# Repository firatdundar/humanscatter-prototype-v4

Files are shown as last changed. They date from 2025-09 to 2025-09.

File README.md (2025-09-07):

# Humanscatter v4 — Low-Power Backscatter Wireless Communication Prototype  
**Summer Research Project at RISE Research Institutes of Sweden**  

<p align="center">
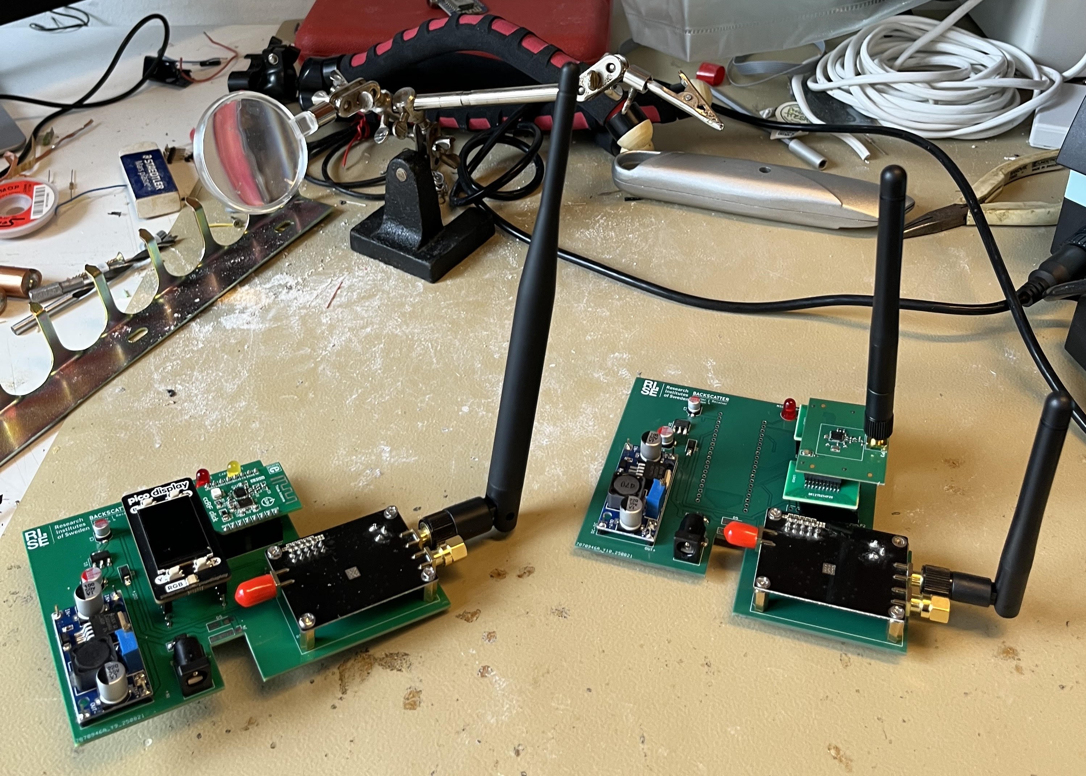
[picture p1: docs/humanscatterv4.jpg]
Humanscatter v4.1 and v4.2 Prototypes
  
</p>

Humanscatter v4 is an **enhanced version** of the [original Humanscatter project](https://github.com/amau75/Humanscatter), developed as part of a **summer research internship** at **RISE Research Institutes of Sweden**.  
This work focuses on **improving the range, reliability, and power stability** of a **low-power backscatter wireless communication prototype** for battery-free IoT applications.

---

## What's New in Humanscatter v4

### **v4.1**
- **Carrier module upgraded** to an **ADF4351 RF synthesizer** instead of CC2500.
- Added **AMS1117 3.3 V LDO regulator** for **cleaner and more stable power**.
- Improved range thanks to **better carrier control** and lower noise.
- Redesigned **KiCad PCB design** and updated **Raspberry Pi Pico firmware**.

### **v4.2**
- Built on top of v4.1 enhancements.
- **Receiver module upgraded** to a **CC2500 EMK evaluation kit**.
- Switched from a **trace antenna** to an **SMA-based external antenna** for better sensitivity.
- **AMS1117 regulator retained** for stable RF power delivery.
- Further improved range, carrier stability, and signal reliability.

---

## Hardware Overview

| Component | Original | v4.1 | v4.2 |
|---|---|---|---|
| **Carrier Module** | CC2500 | **ADF4351** (RF synthesizer) | **ADF4351** (RF synthesizer) |
| **Receiver Module**  | CC2500 (trace antenna) | CC2500 (trace antenna) | **CC2500 EMK** + **SMA antenna** |
| **Voltage Regulator**| None | **AMS1117 (3.3 V LDO)** | **AMS1117 (3.3 V LDO)** |
| **Microcontroller**  | Raspberry Pi Pico | Raspberry Pi Pico | Raspberry Pi Pico |
| **Antenna Type** | Trace PCB antenna | Trace PCB antenna | **SMA external antenna** |
| **PCB Design** | Original Humanscatter PCB  | Updated KiCad design | Updated KiCad design |

---

## Repository Structure

```

humanscatter-v4/
│
├── humanscatter-v4.1/
│   ├── kicad/           # KiCad schematic + PCB files for v4.1
│   └── firmware/        # Updated Raspberry Pi Pico code for v4.1
│
├── humanscatter-v4.2/
│   ├── kicad/           # KiCad schematic + PCB files for v4.2
│   └── firmware/        # Updated Raspberry Pi Pico code for v4.2
│
└── README.md            # This file

````

---

## Getting Started

### 1. Clone the Repository
```bash
git clone https://github.com/yourusername/humanscatter-v4.git
cd humanscatter-v4
````

### 2. Open KiCad Project

```bash
cd humanscatter-v4.1/kicad
open humanscatter-v4.1.kicad_pro
```

*(Same for `humanscatter-v4.2`.)*

### 3. Build and Flash Firmware

* Follow the same steps as in the [original Humanscatter project](https://github.com/amau75/Humanscatter).
* Replace the firmware files with the updated ones provided in the **`firmware/`** folder.
* Flash the code to the **Raspberry Pi Pico** using **Thonny** or any other MicroPython flashing tool.

##  Experimental Improvements

The key goals of this research were to **improve range**, **stability**, and **power delivery**.
Using the **ADF4351 RF synthesizer**, **AMS1117 regulator**, and an **SMA-based CC2500 EMK receiver**:

* Achieved **greater link distance** compared to original version.
* Improved **signal-to-noise ratio (SNR)**.
* Reduced **carrier frequency drift**.
* Increased **overall communication reliability**.

---

## License

This project builds upon the original [Humanscatter](https://github.com/amau75/Humanscatter)
and is released under the **CERN-OHL-P** open hardware license.

---

## Acknowledgements

* **Dr. Fehmi Ben Abdesslem** — for supervision and continuous support throughout the summer research
* **Amaury Couderc** — for the original Humanscatter project and guidance
* **RISE Research Institutes of Sweden** — for hosting and supporting the project

---

## 🔗 References

* Original Humanscatter repository: [https://github.com/amau75/Humanscatter](https://github.com/amau75/Humanscatter)
* ADF4351 RF Synthesizer Module: [Datasheet](https://www.analog.com/media/en/technical-documentation/data-sheets/ADF4351.pdf)
* CC2500 RF Transceiver: [Datasheet](https://www.ti.com/product/CC2500)
* AMS1117 Voltage Regulator: [Datasheet](http://www.advanced-monolithic.com/pdf/ds1117.pdf)

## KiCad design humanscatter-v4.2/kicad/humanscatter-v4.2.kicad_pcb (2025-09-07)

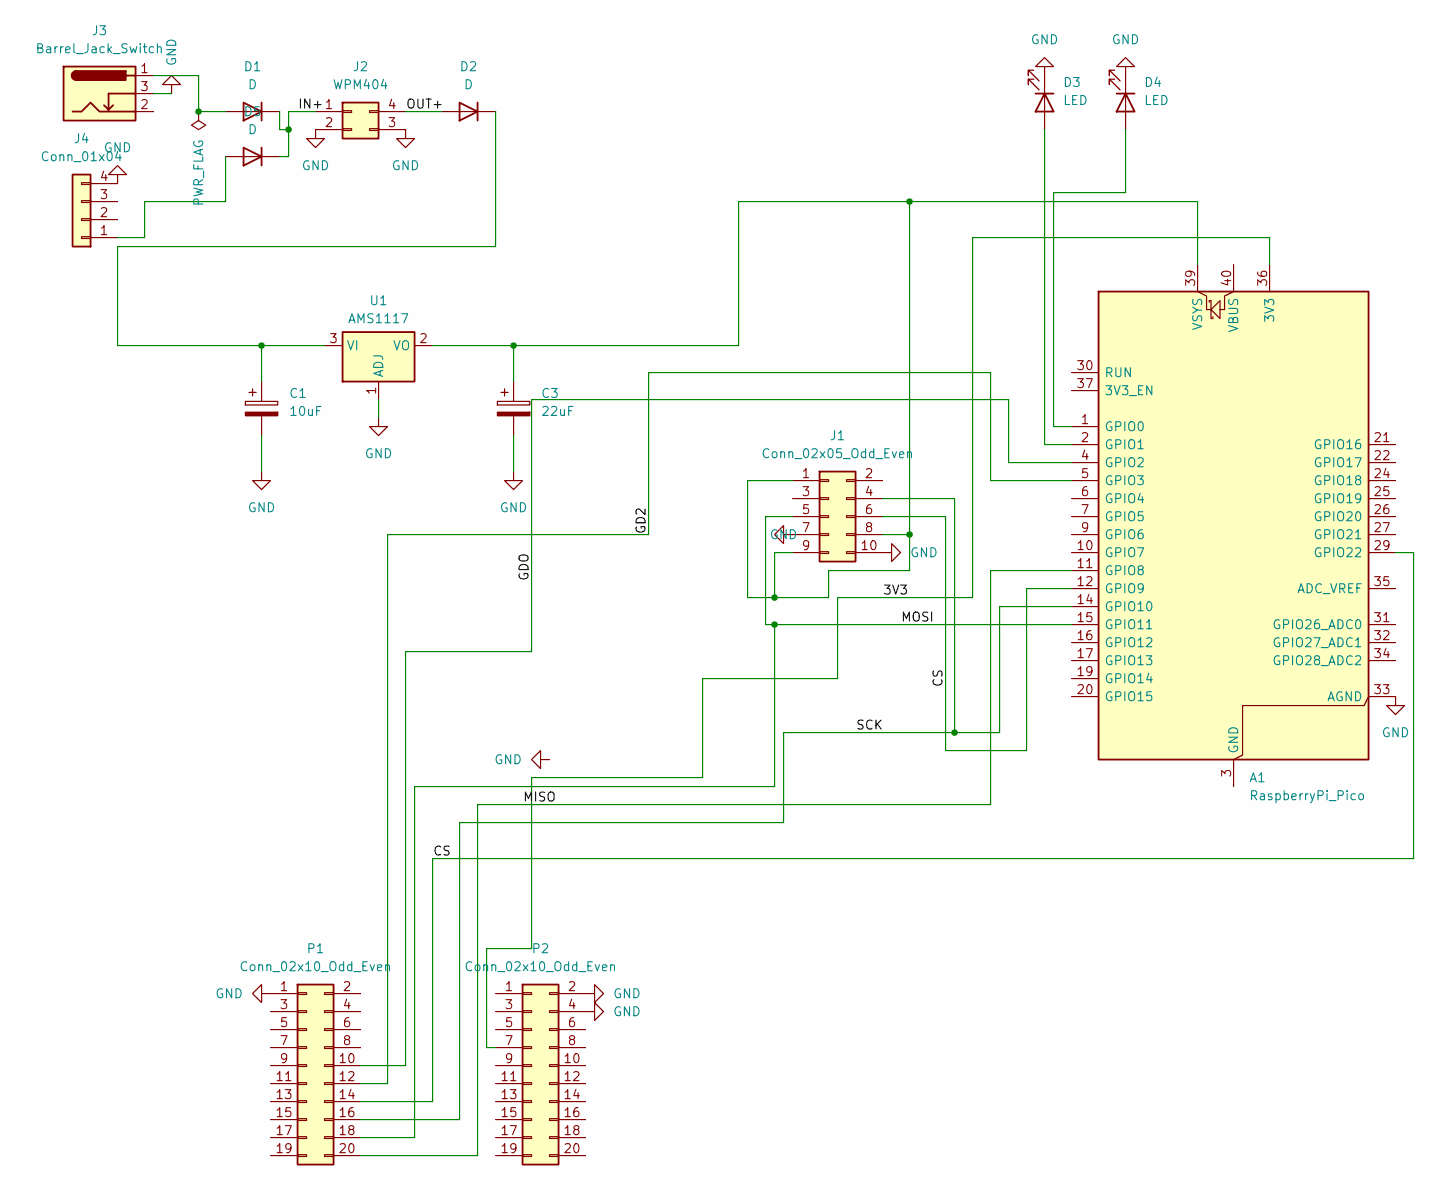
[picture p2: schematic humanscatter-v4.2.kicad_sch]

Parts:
A1: RaspberryPi_Pico; RaspberryPi_Pico_Common_THT
C1: 10uF; CP_Elec_6.3x5.4
C3: 22uF; CP_Elec_5x5.4
D1, D2, D5: D; D_SMA_Handsoldering
D3, D4: LED; LED_D5.0mm
J1: Conn_02x05_Odd_Even; PinSocket_2x05_P2.54mm_Vertical
J2: WPM404; WPM404_New
J3: Barrel_Jack_Switch; BarrelJack_Wuerth_6941xx301002
J4: Conn_01x04; PinHeader_1x04_P2.54mm_Vertical
P1, P2: Conn_02x10_Odd_Even; PinHeader_2x10_P1.27mm_Vertical
U1: AMS1117; SOT-223-3_TabPin2

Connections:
/3V3: A1.36 (3V3), P2.7
/CS: A1.12 (GPIO9), A1.29 (GPIO22), J1.6, P1.14
/GD2: A1.5 (GPIO3), P1.12
/GDO: A1.4 (GPIO2), P1.10
/IN+: D1.1 (K), D5.1 (K), J2.1
/MISO: A1.11 (GPIO8), P1.20
/MOSI: A1.15 (GPIO11), J1.5, P1.18
/OUT+: D2.2 (A), J2.4
/SCK: A1.14 (GPIO10), J1.4, P1.16
GND: A1.33 (AGND), C1.2, C3.2, D3.1 (K), D4.1 (K), J1.7, J1.10, J2.2, J2.3, J3.3, J4.4, P1.1, P2.2, P2.4, U1.1 (ADJ)
unnamed: A1.3 (GND), A1.8 (GND), A1.13 (GND), A1.18 (GND), A1.23 (GND), A1.28 (GND), A1.38 (GND)
unnamed: A1.1 (GPIO0), D4.2 (A)
unnamed: A1.2 (GPIO1), D3.2 (A)
unnamed: A1.39 (VSYS), C3.1, J1.1, J1.8, J1.9, U1.2 (VO)
unnamed: D1.2 (A), J3.1
unnamed: C1.1, D2.1 (K), U1.3 (VI)
unnamed: D5.2 (A), J4.1

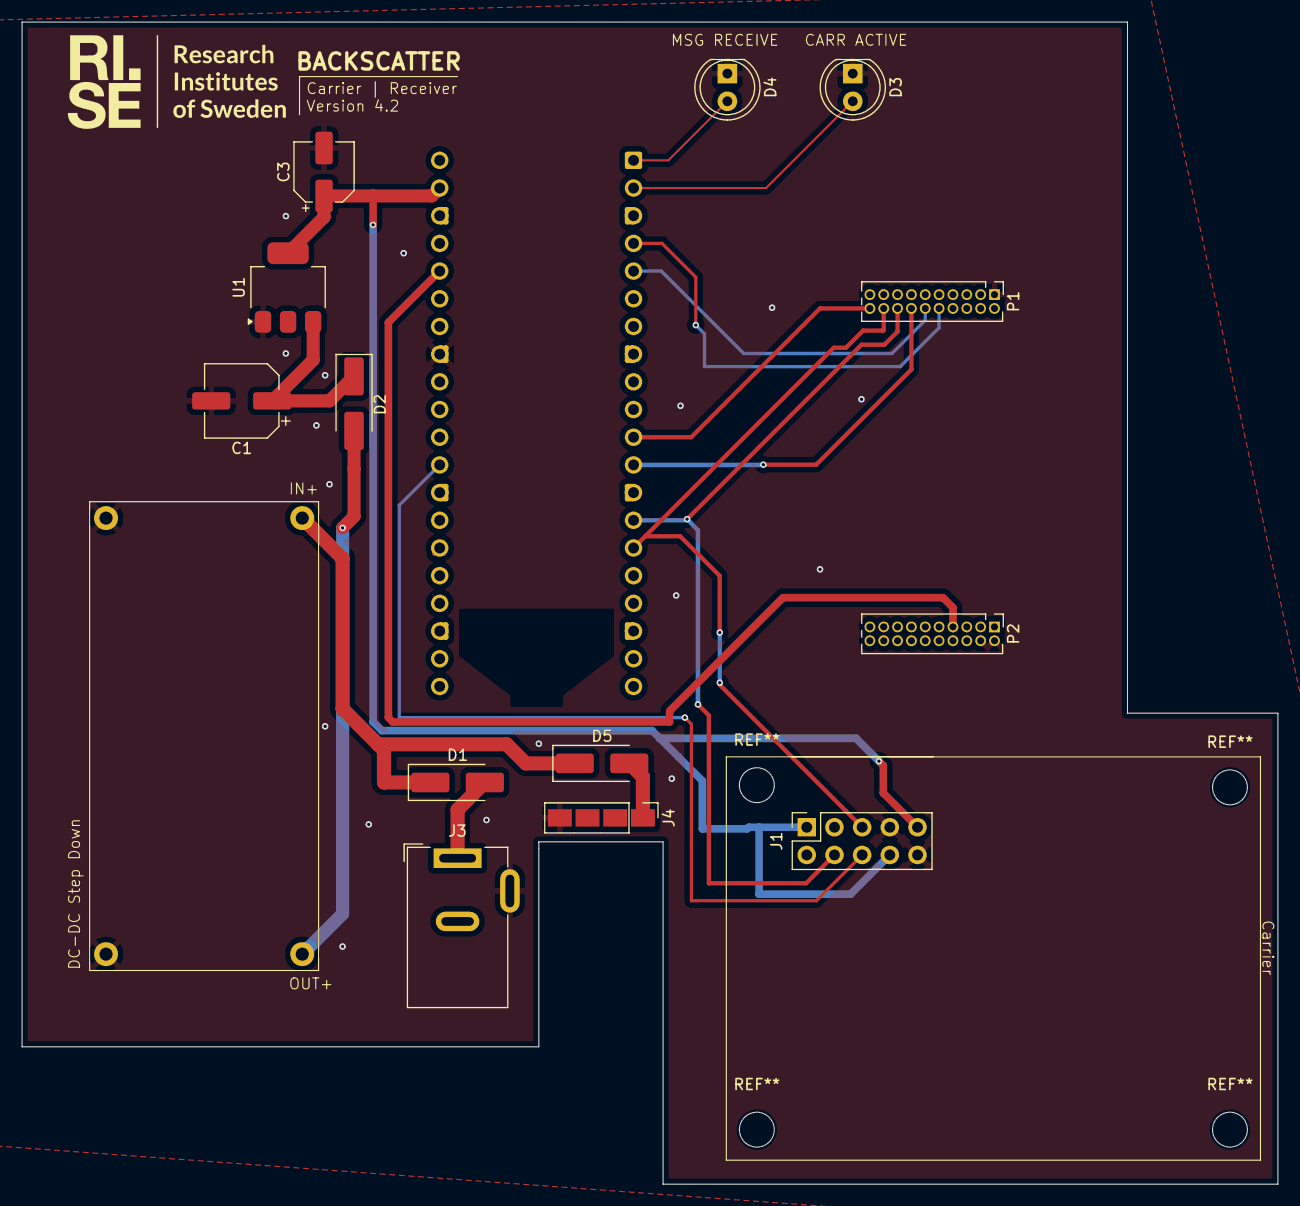
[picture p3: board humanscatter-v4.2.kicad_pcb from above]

Board: 2 copper layers, 115.2 x 106.6 mm, 15 parts (1 on the bottom side), 17 nets.

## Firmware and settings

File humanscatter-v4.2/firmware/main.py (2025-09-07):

import time
import machine
from machine import Pin, SPI

# ====================== SAFE IMPORTS ======================
try:
    from picographics import PicoGraphics, DISPLAY_PICO_DISPLAY, PEN_P4
except ImportError:
    print("[ERROR] PicoGraphics module not found! Check your UF2 firmware.")
    PicoGraphics = None

try:
    import carrier
    import receiver
    import display
except Exception as e:
    print("[ERROR] Failed to import local modules:", e)
    carrier = None
    receiver = None
    display = None

# ====================== BOOT DELAY ======================
print("[DEBUG] Waiting 3s before starting...")
time.sleep(3)

# ====================== PINS ======================
LED_CARRIER_PIN = 1   # GPIO1 → Carrier active LED
LED_MESSAGE_PIN = 0   # GPIO0 → Message received LED

RX_SCK = 10
RX_MISO = 8
RX_MOSI = 11
CS_RX_PIN = 22
GDO0_PIN = 2
GD2_PIN = 3   # optional

carrier_timeout = 20  # seconds

# ====================== LED SETUP ======================
try:
    LED_CARRIER = Pin(LED_CARRIER_PIN, Pin.OUT)
    LED_MESSAGE = Pin(LED_MESSAGE_PIN, Pin.OUT)

    # Reset LEDs
    LED_CARRIER.value(0)
    LED_MESSAGE.value(0)

    print("[DEBUG] LEDs initialized successfully!")

    # Test LEDs separately at boot
    print("[DEBUG] Testing LEDs...")
    LED_CARRIER.value(1)
    time.sleep(0.3)
    LED_CARRIER.value(0)
    time.sleep(0.2)
    LED_MESSAGE.value(1)
    time.sleep(0.3)
    LED_MESSAGE.value(0)
    print("[DEBUG] LED test complete!")

except Exception as e:
    print("[ERROR] Failed to initialize LEDs:", e)

# ====================== VBUS / POWER DETECTION ======================
VBUS_PIN = 24   # Physical pin 40 → VBUS sense
try:
    VBUS = machine.Pin(VBUS_PIN, machine.Pin.IN)
except:
    VBUS = None
    print("[WARN] VBUS pin not available!")

def is_usb_powered():
    if VBUS is None:
        return False
    return VBUS.value() == 1

# ====================== POWER LED INDICATOR ======================
try:
    if is_usb_powered():
        print("[DEBUG] USB power detected → Turning GPIO0 LED ON")
        LED_MESSAGE.value(1)
    else:
        print("[DEBUG] VSYS (external) power detected → Turning GPIO0 LED ON")
        LED_MESSAGE.value(1)
except Exception as e:
    print("[ERROR] Failed to set power LED:", e)


# ====================== DISPLAY SETUP ======================
display_humanscatter = None
color = None

if display and PicoGraphics:
    try:
        print("[DEBUG] Initializing Pico Display...")
        display_humanscatter, color = display.setup_screen()
        print("[DEBUG] Pico Display initialized successfully!")
    except Exception as e:
        print("[ERROR] Failed to initialize display:", e)
else:
    print("[WARN] Skipping display setup — PicoGraphics or display.py missing!")

# ====================== SPI RECEIVER SETUP ======================
radio = None
CS_RX = None
try:
    print("[DEBUG] Setting up SPI for CC2500 receiver...")
    radio = SPI(
        1,
        baudrate=5_000_000,
        polarity=0,
        phase=0,
        bits=8,
        firstbit=SPI.MSB,
        sck=Pin(RX_SCK),
        mosi=Pin(RX_MOSI),
        miso=Pin(RX_MISO)
    )
    CS_RX = Pin(CS_RX_PIN, Pin.OUT)
    print("[DEBUG] SPI configured successfully!")
except Exception as e:
    print("[ERROR] Failed to configure SPI:", e)

# ====================== CARRIER SETUP ======================
if carrier:
    try:
        print("[DEBUG] Setting up ADF4351 carrier...")
        carrier.setup_TX()
        print("[DEBUG] ADF4351 setup complete!")
    except Exception as e:
        print("[ERROR] Carrier setup failed:", e)

# ====================== RECEIVER SETUP ======================
if receiver and radio and CS_RX:
    try:
        print("[DEBUG] Setting up CC2500 receiver...")
        receiver.setup_RX(radio, CS_RX, GDO0_PIN)
        print("[DEBUG] CC2500 receiver setup complete!")
    except Exception as e:
        print("[ERROR] Receiver setup failed:", e)

time.sleep_us(100)

# ====================== START CARRIER ======================
if carrier:
    try:
        print("[DEBUG] Starting carrier TX...")
        carrier.start_carrier_TX()
        LED_CARRIER.value(1)  # Turn carrier LED ON
        print("[DEBUG] Carrier started successfully!")
    except Exception as e:
        print("[ERROR] Failed to start carrier:", e)

# ====================== START RECEIVER ======================
if receiver and radio and CS_RX:
    try:
        print("[DEBUG] Starting receiver listening mode...")
        receiver.start_listen_RX(radio, CS_RX)
        receiver.event_RX = "no_reception"
        print("[DEBUG] Receiver listening mode active!")
    except Exception as e:
        print("[ERROR] Failed to start receiver:", e)

# ====================== INITIAL EVENTS ======================
if receiver and carrier:
    receiver.event_RX = "no_reception"
    carrier.event_TX = "no_timeout"
    print(f"[DEBUG] Initial RX event: {receiver.event_RX}")
    print(f"[DEBUG] Initial TX event: {carrier.event_TX}")

# ====================== MAIN LOOP ======================
cnt = 1
cnt2 = 0

if receiver and carrier:
    try:
        receiver.dummy_message_generator()
        carrier.carrier_timer(carrier_timeout)
    except Exception as e:
        print("[ERROR] Failed to start timers:", e)

print("[DEBUG] Entering main loop...")

try:
    while True:
        # If receiver got a message
        if receiver and receiver.event_RX == "reception":
            try:
                print("[DEBUG] Message received!")
                message = receiver.decode_packet_RX(
                    radio, CS_RX, receiver.RX_BUFFER_SIZE, receiver.Message()
                )

                # Blink message LED when message is received
                LED_MESSAGE.value(1)
                time.sleep_ms(100)
                LED_MESSAGE.value(0)

                # Demo messages
                if cnt2 == 0:
                    message.data = "Hello je backscatte comment ça va le sang"
                    message.RSSI += 5
                elif cnt2 == 1:
                    message.data = "Salut je suis Amaury, étudiant à RISE"
                    message.RSSI += 3
                elif cnt2 == 2:
                    message.data = "J'adore la Suède, super pays!"
                    message.RSSI += 8

                cnt2 = (cnt2 + 1) % 3

                receiver.print_RX(message)

                if display_humanscatter:
                    display.print_msg(display_humanscatter, message, color)

                time.sleep_ms(2000)
                receiver.start_listen_RX(radio, CS_RX)
                receiver.event_RX = "no_reception"
                cnt = 1
            except Exception as e:
                print("[ERROR] Failed during reception:", e)

        # If no messages yet
        elif receiver and receiver.event_RX == "no_reception":
            if cnt:
                print("[DEBUG] Waiting for messages...")
                if display_humanscatter:
                    display.print_waiting(display_humanscatter, "WAITING", color)
                cnt = 0

        # Carrier timeout
        elif carrier and carrier.event_TX == "timeout":
            print("[DEBUG] Carrier timeout! Stopping...")
            carrier.stop_carrier_TX()
            LED_CARRIER.value(0)  # Turn carrier LED OFF
            if display_humanscatter:
                display.print_carrier_timeout(display_humanscatter, color)
            break

        time.sleep(0.05)

except Exception as e:
    print("[FATAL] Crash in main loop:", e)
    print("[INFO] Entering safe idle mode...")
    while True:
        time.sleep(1)  # Keep USB REPL alive

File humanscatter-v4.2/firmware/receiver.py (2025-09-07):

import time
import carrier
import machine
import math
from machine import Pin, SPI, ADC, Timer
from picographics import PicoGraphics, DISPLAY_PICO_DISPLAY, PEN_P4

#================ VARIABLES =============

# Print Receiver Radio Configuration
config_prints = False

# Radio Parameters
BAUDRATE = 100000
F_XOSC = 26000000
CARRIER_FEQ = 2450000000
RX_BUFFER_SIZE = 64

# Values
r_data = 100000
bw = 794444
f_dev = 347222
f_carrier = 6597222

# --- NEW PIN CONFIGURATION ---
PIN_SCK = 10
PIN_MOSI = 11
PIN_MISO = 8
PIN_CS = 22
PIN_GDO0 = 2
PIN_GD2 = 3

# SPI initialization
spi_rx = SPI(
    1,
    baudrate=BAUDRATE,
    polarity=0,
    phase=0,
    bits=8,
    firstbit=SPI.MSB,
    sck=Pin(PIN_SCK),
    mosi=Pin(PIN_MOSI),
    miso=Pin(PIN_MISO)
)

# Chip Select Pin
cs_rx = Pin(PIN_CS, Pin.OUT)
cs_rx.value(1)  # Active low

# Interrupt pins
gdo0_pin = Pin(PIN_GDO0, Pin.IN)
gd2_pin = Pin(PIN_GD2, Pin.IN)

#================ REST OF CODE =============

# Strobes
SIDLE = 0x36    #Idle mode of radio
SRX = 0x34      #Receive mode of radio
SFRX = 0x3A     #Clear FIFO
SRES = 0x30     #Reset radio

# Registers
cc2500_receiver_settings=[[0x02, 0x06],
                          [0x08, 0x05],
                          [0x0b, 0x0A],
                          [0x0e, 0x7C],
                          [0x0f, 0x08],
                          [0x10, 0x0B],
                          [0x11, 0xF1],
                          [0x12, 0x03],
                          [0x13, 0x23],
                          [0x14, 0xFF],
                          [0x15, 0x76],
                          [0x18, 0x18],
                          [0x19, 0x1D],
                          [0x1a, 0x1C],
                          [0x1b, 0xC7],
                          [0x1c, 0x00],
                          [0x1d, 0xB0],
                          [0x21, 0xB6],
                          [0x25, 0x00],
                          [0x26, 0x11]]


class Message:
    data = ""
    overflow = 0
    RSSI = 0
    CRC = 0
    length = 0
    sequence = 0
    link_quality_indicator = 0

#================ FUNCTIONS =============

#-------------- setup functions --------------

def setup_RX(spi, CS, Pin_interrupt):
    write_strobe_RX(spi, CS, SRES)
    time.sleep_us(100)
    write_strobe_RX(spi, CS, SIDLE)
    
    write_register_RX(spi, CS, cc2500_receiver_settings)
    if (config_prints):
        print("set spi config  RX:")
        print([f"0x{byte:02X}" for pair in cc2500_receiver_settings for byte in pair])
        print(cc2500_receiver_settings)
    set_irq_RX(Pin_interrupt)
    set_frequency_RX(spi, CS, f_carrier + CARRIER_FEQ)
    set_freq_deviation_RX(spi, CS, f_dev)
    set_datarate_RX(spi, CS, r_data)
    set_filter_bandwidth_RX(spi, CS, bw)
    write_register_RX(spi, CS, [[0x10,0x0B]])

def interrupt_handler_RX(Pin):
    global event
    event = "reception"
    
def set_irq_RX(Pin_interrupt):
    interrupt_pin = machine.Pin(Pin_interrupt, mode=Pin.IN)
    interrupt_pin.irq(trigger=Pin.IRQ_FALLING,handler=interrupt_handler_RX)

#-------------- radio config functions --------------
    
def set_datarate_RX(spi, CS, r_data):
    write_strobe_RX(spi, CS, SIDLE)
    drate_e = int(math.log2((r_data * (1 << 20)) / F_XOSC))
    drate_m = int((r_data * (1<<28)) / (F_XOSC * (1 << drate_e)) - 256.0)
    r_data_calculated = int(((256.0 + drate_m) * (1<<drate_e) * F_XOSC) / (1<<28)) 
    mdmcfg3 = read_register_RX(spi, CS, 0x10)[0];
    msg = [[0x10, (mdmcfg3 & 0xf0) + (drate_e & 0x0f)], [0x11, drate_m]]
    write_register_RX(spi, CS, msg)
    if (config_prints):
        print(f"set RX r_data : [{drate_e} {drate_m}] {r_data_calculated}")
        print("\nset_datarate RX")
        print([f"0x{byte:02X}" for pair in msg for byte in pair])
        print(msg)

def set_filter_bandwidth_RX(spi, CS, bw):
    write_strobe_RX(spi, CS, SIDLE)
    chanbw_e = int(math.log2(F_XOSC / ((1<<5) * bw) / math.log2(2.0)))
    chanbw_m = int(F_XOSC / (8.0 * bw * (1<<chanbw_e)) - 4.0)
    bw_calculated = int(F_XOSC / (8.0 * (4.0 + chanbw_m) * (1<<chanbw_e)))
    mdmcfg3 = read_register_RX(spi, CS, 0x10)[0];
    msg = [[0x10, ((chanbw_e & 0x03)<<6) + ((chanbw_m & 0x03)<<4) + (mdmcfg3 & 0x0f)]]
    write_register_RX(spi, CS, msg)
    if (config_prints):
        print(f"set RX bw: [{chanbw_e} {chanbw_m}] {bw_calculated}")
        print("\nset_filter_bandwidth RX")
        print([f"0x{byte:02X}" for pair in msg for byte in pair])
        print(msg)

def set_freq_deviation_RX(spi, CS, f_dev):
    write_strobe_RX(spi, CS, SIDLE)  
    deviation_e = int(math.log2(f_dev * (1<<14) / F_XOSC))
    deviation_m = int(f_dev * (1<<17) / ((1<<deviation_e) * F_XOSC) - 8.0)
    f_dev_calculated = int(F_XOSC * (8.0 + deviation_m + 1.0) * (1<<deviation_e) / (1<<17))
    msg = [[0x15, ((deviation_e & 0x07)<<4) + (deviation_m & 0x07)]]
    write_register_RX(spi, CS, msg)
    if (config_prints):
        print(f"set RX f_dev: [{deviation_e} {deviation_m}] {f_dev_calculated}")
        print("\nset_frequency_deviation RX")
        print([f"0x{byte:02X}" for pair in msg for byte in pair])
        print(msg)

def set_frequency_RX(spi, CS, frequency):
    write_strobe_RX(spi, CS, SIDLE)
    freq = int(frequency * ((1<<16) / F_XOSC))
    channel = 0
    channspc_e = 0
    channspc_m = int(((frequency * (1 << 16)) / F_XOSC - freq - (1 << 6)) * (1 << 2))
    frequency_calculated = int(F_XOSC * (freq + channel * (256 + channspc_m) / (1 << 2)) / (1 << 16))
    #
    mdmcfg1 = read_register_RX(spi, CS, 0x13)[0];
    msg = [[0x0a, channel],
           [0x0d, ((freq & 0x007f0000)>>16)],
           [0x0e, ((freq & 0x0000ff00)>>8)],
           [0x0f, (freq & 0x000000ff) - 1],
           [0x13, (mdmcfg1 & 0xf0) + (channspc_e & 0X03) + 32],
           [0x14, (channspc_m)]]
    write_register_RX(spi, CS, msg)
    if (config_prints):
        print(f"set RX frequency [{freq} {channel} {channspc_e} {channspc_m}] {frequency_calculated}")
        print("\nset_frequency RX")
        print([f"0x{byte:02X}" for pair in msg for byte in pair])
        print(msg)
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

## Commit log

2025-09-07 KiCad design files
    [humanscatter-v4.1.kicad_pcb, humanscatter-v4.1.kicad_sch, humanscatter-v4.2.kicad_pcb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]
2025-09-07 Uploaded code and updated the repo structure
    [humanscatter-v4.1.kicad_pcb, humanscatter-v4.1.kicad_sch, humanscatter-v4.2.kicad_pcb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]
